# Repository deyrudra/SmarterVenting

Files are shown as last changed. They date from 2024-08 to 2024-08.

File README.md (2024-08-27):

# SmarterVenting
This is a Smarter Venting system that uses a hierarchy for prioritization of when to open vents, and at which degree.

*Note*: This is the main directory, which uses the esp8266 d1 mini microcontroller. The esp32 directory, using the LolinD32 (esp32) microcontroller.

Hierarchy:
1. Priority Rooms
   - Rooms above a garage.
   - Rooms with lack of insulation
   - Rooms with heating/cooling issues due to the size.
2. Secondary Rooms
   - Rooms that still need heating/cooling, but do not have any issues stated above.
3. Thermostat Location
  - Depending on the location, it could be an array of vents, or a singular vent.

Hierarchy concept:
- The general concept is as simple as reordering the rooms in which they get cool/hot air through.
- To prioritize the location of the thermostat last is to let the HVAC system run without stopping up until the Thermostat location reaches it's desired temperature.
  - This allows the other rooms to cooled/heated to it's desired temperature first.
 
Fallback:
- The temperature of the air coming from the vent; that is the limit to which you can cool/heat your room.

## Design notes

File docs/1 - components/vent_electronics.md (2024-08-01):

## Essential Parts (Mandatory)
- D1 Mini ESP8266
- MG90s Servo Motor

## Power Options (Mandatory, Choose One)
1. Plugged in USB-C or Micro-USB
    - Power Brick
    - USB-C or Micro-USB cable
2. Plugged in barrel connector w/ DC shield
    - D1 Mini DC Power Shield
    - Barrel Jack Power Cable
3. Battery Powered barrel connector w/ DC shield + AA batteries
    - D1 Mini DC Power Shield
    - Battery Holder to Barrel Jack 
    - AA Batteries (Prefereabbly Rechargeable)
4. Battery Powered USB-C or Micro-USB w/ PowerBank (my preffered option)
    - D1 Mini DC Power Shield
    - Powerbank (high capacity)

## My Personal List (This is just how I did it to make it dirt cheap)
- Some Items I bought, their quantity, and their price in CAD.
    - D1 mini v2
        - 1x 3.17
        - 3x 1.18
        - Total: 6.71
    - D1 mini v3
        - 4x 2.09
        - Total: 9.98
    - DHT11
        - 5x 0.89
        - Total: 4.45
    - US usb plug
        - 10x 1.24
        - Total: 12.40
    - Charging Cables USB C #1
        - 5x 1.00
        - 5x 1.00
        - Total: 10.00
    - Full Metal Servo 9g 5x
        - 5x 2.47
        - Total: 12.35
    - PowerBank 
        - 5x 7.99
        - Total: 45.15
    - PLA 1kg
        - Total: 15
- So for me the prices for the items are:
    - Single Vent Price:
        - 2.09
        - 2.47
        - 7.99
        - 0.25 x 15
        - Total: $16.30
    - Single Temperature Monitor Price:
        - 2.14
        - 4.45
        - 0.89
        - 1.00
        - 1.24
        - Total: $9.72
- For the powerbank, it's just a generic powerbank cover for a 2600mAh 18650 Rechargeable Battery.
    - The dimensions I found online are:
        - 96 x 24 x 23mm

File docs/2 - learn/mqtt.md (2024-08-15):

# MQTT
- MQTT stands for Message Queuing Telemetry Transport
- Messaging protocol used for communcation between IoT devices.
- Features of MQTT:
    - Publish/Subscribe Model:
        - Clients (our devices) *publish* messages to a model called a **broker**. This broker then redistributes these message to all subscribers of their respective topics.
    - Lightweight
    - Reliable
    - Scalability

- Publish/Subscribe (PUB/SUB) Model in Depth
    - Broker:
        - Receives all messages from publishers.
        - Filters the received messages based on topics.
        - Distributes the messages to appropriate subscribers
    - Topics:
        - A topic is just a string. It serves to route messages.
        - Topics resemble file paths: `home/kitchen/temperature`.
            - This means topics are hierarchial.
        - Publishers send messages to specific topics, subscribers express interest in one or more topics.
        
    - Publisher:
        - A device or application that sends messages to the broker under specific topics.
        - These publishers are only concerned about sending their data.
            - There is no concern about who the subscribers are, just need to send the data to the broker with the topic.
        - Ex. temperature sensor in smart home can publlish readings to the topic `home/kitchen/temperature`.
    - Subscriber:
        - A device or application that has interest in one or more topics.
        - Subscribers receive all messages published to their topic.
        - Ex. a smart thermostat might subscribe to `home/kitchen/temperature` to receive updates and adjust the temperature accordingly.
        - Under the hierarchy, if a subscriber chooses to, they can subscribe to multiple topics at once, without having to specifiy each one. They can just simply subscribe to `home/kitchen/#`. The `#` refers to all subtopics under the `home/kitchen` topic.

- QoS: QoS 1 ensures the message which has been published/subscribed to will establish connection atleast once. (ex. your device runs out of battery and you charge it back up, it will get the message after it's back alive).

- Retain: Allows published packets to keep it's value on the borker, such that the retained flags of the client act as a last save restoration, pulling info from the broker itself.
## Setting up an MQTT Broker on Home Assistant
- The guides I followed:
    - https://www.home-assistant.io/integrations/mqtt/#:~:text=press%20%E2%80%9CPUBLISH%E2%80%9D%20.-,Go%20to%20Settings%20%3E%20Devices%20%26%20services.,Select%20Publish.
    - https://github.com/home-assistant/addons/blob/master/mosquitto/DOCS.md
    - https://www.youtube.com/watch?v=WYyPMHqMV-w

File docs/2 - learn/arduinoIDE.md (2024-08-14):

- Instead of writing the script in a yaml configuartion on Home Assistant, I opted to type a script in Arduino. Then compile it into it's binary, and upload through OTA update on the hosted webserver.

- To start developing in the Arduino IDE for the ESP devices, we need to do the following:
    1. Install ESP8266 and ESP32 Add-on in Arduino IDE
        - Go to Preferences in the IDE, and put `https://dl.espressif.com/dl/package_esp32_index.json, http://arduino.esp8266.com/stable/package_esp8266com_index.json` for additional boards manager URLs.
    2. Open the Boards Manager, and install the ESP32 or ESP8266 boards manager.

- ESP8266WiFi Library: `https://arduino-esp8266.readthedocs.io/en/latest/esp8266wifi/readme.html`
- PubSubClient Library (MQTT): `https://www.arduino.cc/reference/en/libraries/pubsubclient/`

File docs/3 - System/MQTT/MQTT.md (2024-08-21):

# MQTT Topics and Payloads Documentation

## Overview
This document shares details on the project's MQTT topics, payloads, and their respective purposes used in the system. It also indicated when the topic should be QoS 0, QoS 1, and/or retain the published packets.
---

## 1. Topic Structure

### General Topic Format

### Topic Segments:
- **room**: The specific room (e.g., `room_1`, `room_2`).
- **component**: The device or sensor (e.g., `vent`, `dht_sensor`).
- **detail**: Depends on the device/sensor, documented below for the specific component.
- Ex. Full Topic: `room_1/vent/power_mode`
---

## 2. Topics
- Any "Get" topics are to be published by the components, and any "Set" topics are to be subscribed to by the components.

### 2.1 DHT Sensor Component

#### Get Current Temperature Celsius
- **Topic**: `room_x/dht_sensor/temperature/celsius`
- **Payload**: 
  - **Type**: null
  - **Description**: Request the current temperature in celcius from the sensor.
- QoS: 0

#### Get Current Temperature Ferenheit
- **Topic**: `room_x/dht_sensor/temperature/ferenheit`
- **Payload**: 
  - **Type**: null
  - **Description**: Request the current temperature in ferenheit from the sensor.
- QoS: 0

#### Get Current Humidity
- **Topic**: `room_x/dht_sensor/humidity`
- **Payload**: 
  - **Type**: null
  - **Description**: Request the current humidity percentage from the sensor.
- QoS: 0

#### Get Indicator Light Status
- **Topic**: `room_x/dht_sensor/light`
- **Payload**: 
  - **Type**: null
  - **Description**: Requests the current status of the light.
- QoS: 0
- Retain: True

#### Get Calibrate Offset
- **Topic**: `room_x/dht_sensor/calibrate`
- **Payload**: 
  - **Type**: null
  - **Description**: Requests the current temperature offset integer.
- Retain: True
 
#### Set Indicator Light Status
- **Topic**: `room_x/dht_sensor/light`
- **Payload**: 
  - **Type**: ON or OFF
  - **Description**: Sets the current status light to ON or OFF

#### Set Calibrate Offset
- **Topic**: `room_x/dht_sensor/calibrate`
- **Payload**: Any integer between -10 to 10
  - **Type**: int
  - **Description**: Offsets the temperature by an integer.

#### Last Will and Testament (LWT)
- **Topic**: `room_x/dht_sensor/status`
- **Payload**: "offline", "online"
- **QoS**: `1`
- **Retain**: `True`
- **Description**: Sent when the device goes offline unexpectedly.

### 2.2 Vent Component

#### Get Current Vent Angle
- **Topic**: `room_x/vent/angle`
- **Payload**: 
  - **Type**: null
  - **Description**: Request the current vent angle from the component.
- QoS: 1
- Retain: True
#### Get Current Vent Closure State
- **Topic**: `room_x/vent/closure_state`
- **Payload**: 
  - **Type**: null
  - **Description**: Request the current vent closure state from the component.
- QoS: 1
- Retain: True
#### Get Current Vent Power Mode
- **Topic**: `room_x/vent/power_mode`
- **Payload**: 
  - **Type**: null
  - **Description**: Request the current vent power mode from the component.
- QoS: 1
- Retain: True
#### Get Current Vent Climate Mode
- **Topic**: `room_x/vent/climate_mode`
- **Payload**: 
  - **Type**: null
  - **Description**: Request the current vent climate mode from the component.
- QoS: 1
- Retain: True
#### Get Current Vent Control Mode
- **Topic**: `room_x/vent/control_mode`
- **Payload**: 
  - **Type**: null
  - **Description**: Request the current control mode from the component.
- QoS: 1
- Retain: True
#### Get Current Vent Desired Temperature
- **Topic**: `room_x/vent/desired_temp`
- **Payload**: 
  - **Type**: null
  - **Description**: Request the desired temperature from the vent component.
- QoS: 1
- Retain: True

#### Get Desired Temperature Reached State
- **Topic**: `room_x/vent/desired_temp_state`
- **Payload**: 
  - **Type**: null
  - **Description**: Request to see if the desired temperature has been reached, or if it's still ongoing. YES for reached state, NO for not reached yet.
- QoS: 1
- Retain: True

#### Set Current Vent Angle
- **Topic**: `room_x/vent/angle`
- **Payload**: An integer between 0 and 90
  - **Type**: int
  - **Description**: Sets the current vent angle.
- QoS: 1

#### Set Current Vent Closure State
- **Topic**: `room_x/vent/closure_state`
- **Payload**: "Closed", "Semi-Closed", "Open", "Semi-Open"
  - **Type**: String
  - **Description**: Sets the current vent closure state.
- QoS: 1

#### Set Current Vent Power Mode
- **Topic**: `room_x/vent/power_mode`
- **Payload**: "Default", "Eco", "Max-Power"
  - **Type**: String
  - **Description**: Sets the current vent power mode.
- QoS: 1

#### Set Current Vent Climate Mode
- **Topic**: `room_x/vent/climate_mode`
- **Payload**: "Heating", "Cooling"
  - **Type**: String
  - **Description**: Sets the current vent climate mode.
- QoS: 1

#### Set Current Vent Control Mode
- **Topic**: `room_x/vent/control_mode`
- **Payload**: "Auto", "Manual"
  - **Type**: String
  - **Description**: Sets the current control mode.
- QoS: 1

#### Set Current Vent Desired Temperature
- **Topic**: `room_x/vent/desired_temp`
- **Payload**: Any integer between 17 to 26.
  - **Type**: int
  - **Description**: Sets the desired temperature.
- QoS: 1

#### Last Will and Testament (LWT)
- **Topic**: `room_x/vent/status`
- **Payload**: "offline", "online", "eco-online"
- **QoS**: `1`
- **Retain**: `True`
- **Description**: Sent when the device goes offline unexpectedly or due to eco mode.

---

## 3. QoS and Retain Flag

### Quality of Service (QoS)
- **QoS 0**: Best effort, no acknowledgment.
- **QoS 1**: Ensured delivery, message delivered at least once.
- **QoS 2**: Exactly once delivery, message is delivered only once.

### Retain Flag
- **True**: The last message sent on this topic is saved by the broker.
- **False**: The broker does not save the last message.

### Practical Reasons
- QoS: QoS 1 ensures the message which has been published/subscribed to will establish connection atleast once. (ex. your device runs out of battery and you charge it back up, it will get the message after it's back alive).
  - All vent control should be QoS 1 to increase user experience. 
- Retain: Allows published packets to keep it's value on the borker, such that the retained flags of the client act as a last save restoration, pulling info from the broker itself.

---

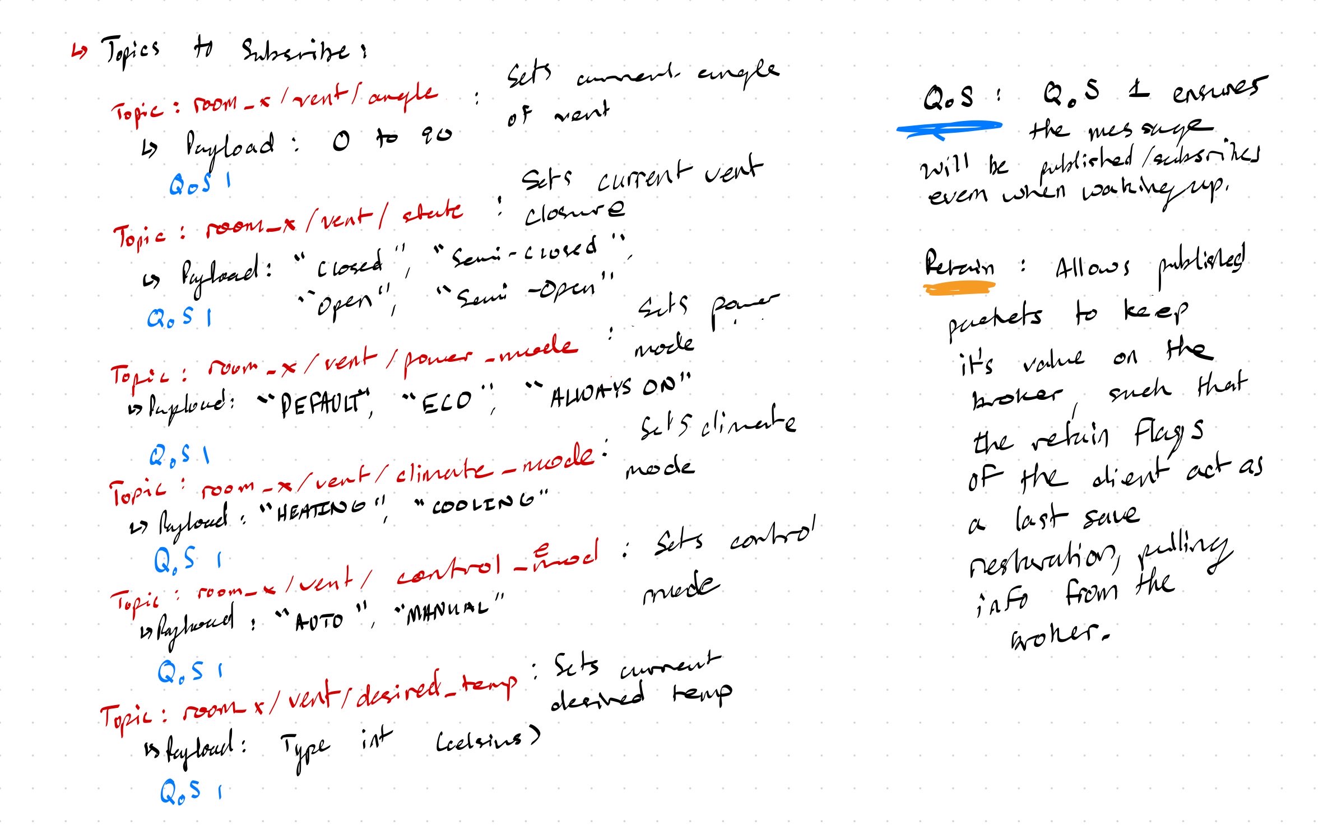
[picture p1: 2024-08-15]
docs/3 - System/MQTT/writtenbrainstorm/image.jpg

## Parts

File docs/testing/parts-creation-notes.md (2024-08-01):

Fins:
Clearance: 0.25cm
Border Margin Shrink: 0.1cm
Overlap: 0.4cm so 0.2 on each one. Also there is only 2 overlap areas.

Short Side
x: 2.87-0.1*2 = 4.3cm 
y: x/2 = 3/2 = 1.5cm

Cutouts must be at: 
Cut 1:
x: 1.6cm
y: 1.6cm
Cut 2:
x: 4.5cm
y: 1.6cm
Cut 3:
x: 7.4cm
y: 1.6cm

x = 1.6cm
y = 1.6cm

Long Side
23.7cm

- There will be 0.4 overlap in the two middle ones.

Joints
Circle: 

Male:

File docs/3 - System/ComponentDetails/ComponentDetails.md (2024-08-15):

# Component Details

## Overview
This document specifies the details of each component in the system. Under each component heading you will find the inner workings of the component and details of all it's processes and automations.

## 1. Vent

### Purpose (Primary Function)

### Processes (All Functions)

### Automations (Automatic executed functions)

## 2. Temperature Sensor

### Purpose (Primary Function)

### Processes (All Functions)

### Automations (Automatic executed functions)

## 3. Homeassistant + MQTT Broker Server

### Purpose (Primary Function)

### Processes (All Functions)

### Automations (Automatic executed functions)

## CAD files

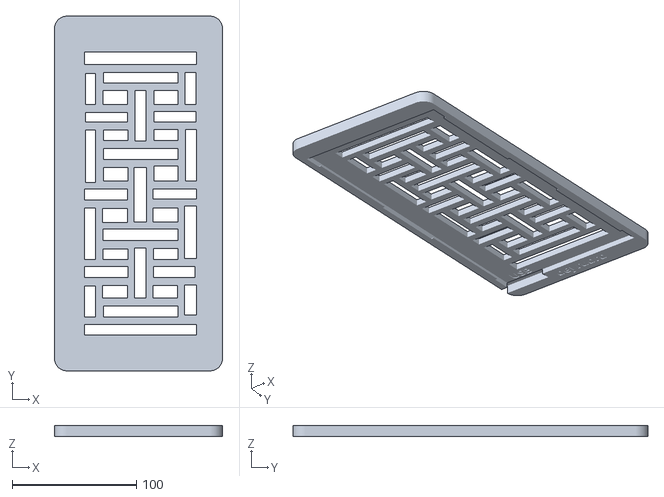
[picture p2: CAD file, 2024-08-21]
models/Register1 (4x10, 3.54x9.61)/Vent Cover/Vent Cover Full.stl
135.0 x 285.0 x 9.00

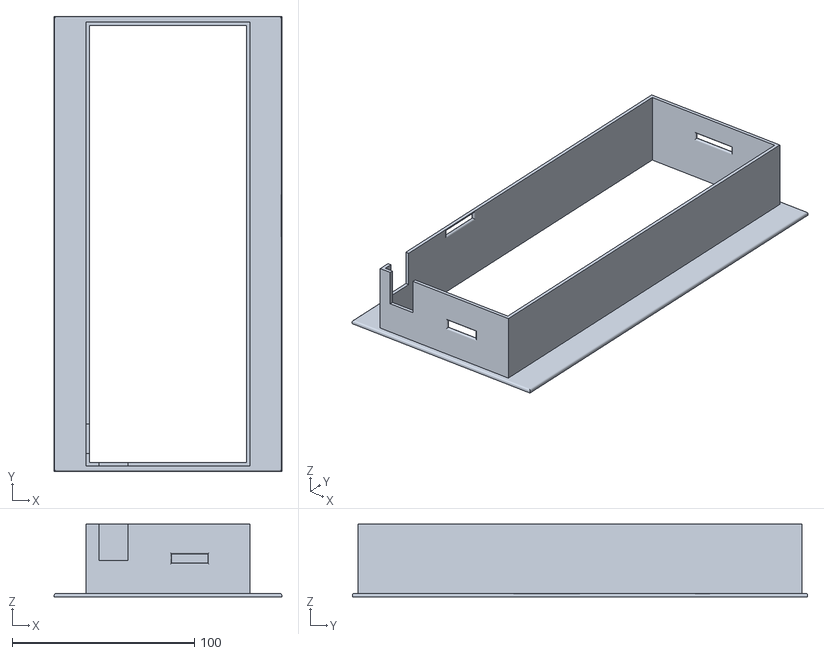
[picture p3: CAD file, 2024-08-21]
models/Register1 (4x10, 3.54x9.61)/Chasis/Chasis Full.stl
125.0 x 250.0 x 40.0

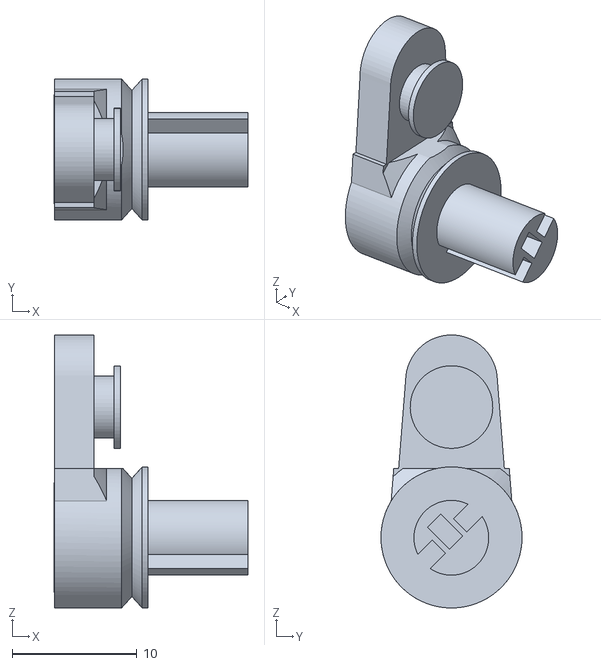
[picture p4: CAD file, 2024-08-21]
models/Register1 (4x10, 3.54x9.61)/Attachments/Lever (x4).stl
15.5 x 11.3 x 21.9

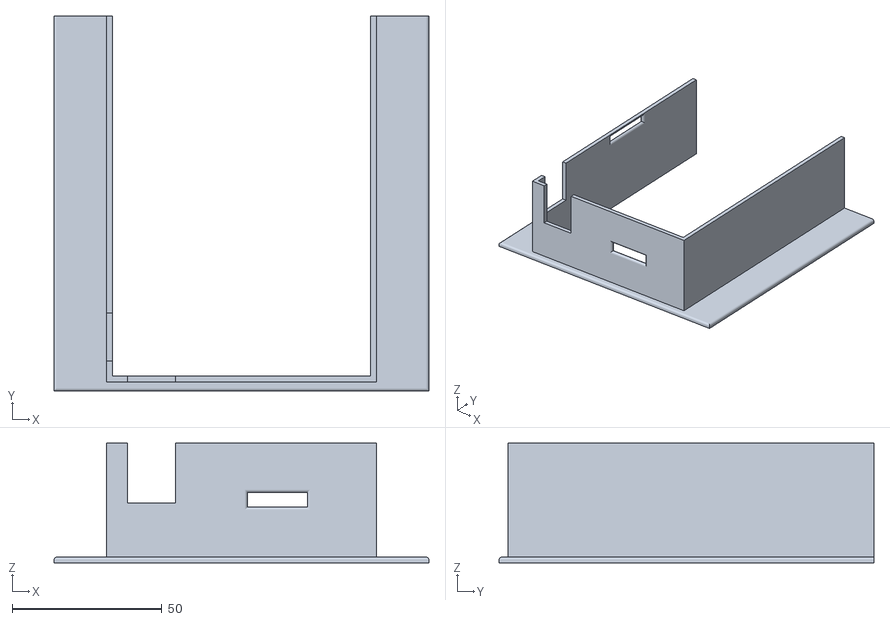
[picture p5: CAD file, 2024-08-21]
models/Register1 (4x10, 3.54x9.61)/Chasis/Chasis Part 1.stl
125.0 x 125.0 x 40.0

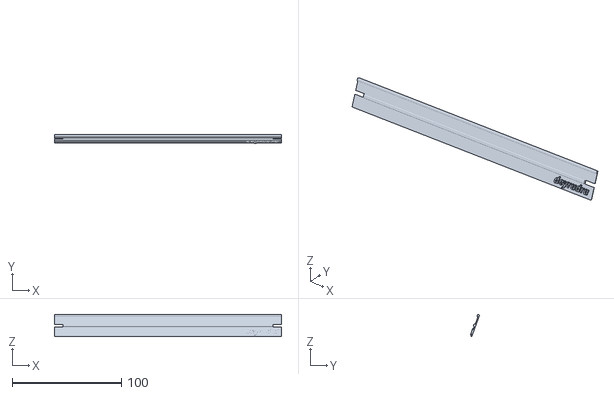
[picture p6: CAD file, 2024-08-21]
models/Register1 (4x10, 3.54x9.61)/Fins/Fin 4 (20.8 cm).stl
208.0 x 8.59 x 20.3

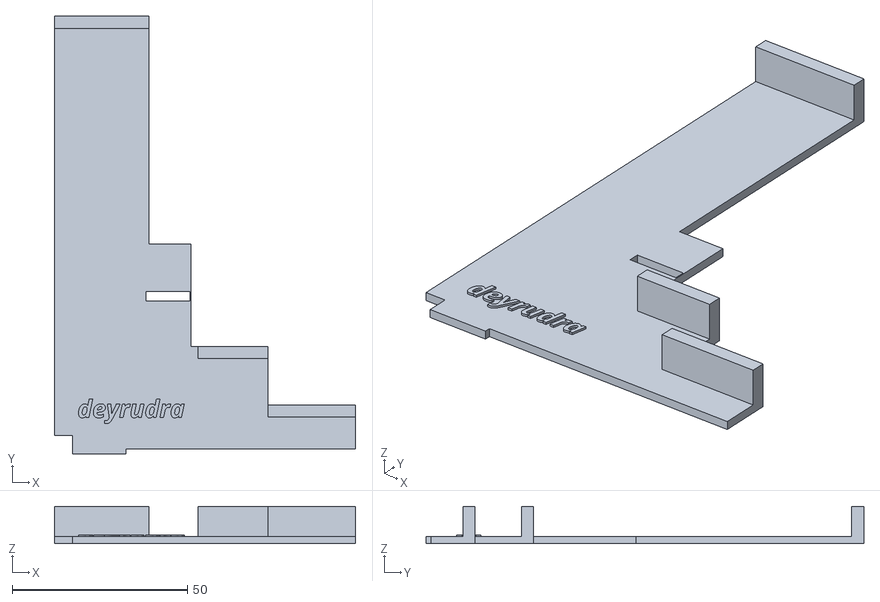
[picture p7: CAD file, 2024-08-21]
models/Register1 (4x10, 3.54x9.61)/Misc/Electronics Cover.stl
86.0 x 125.0 x 10.7

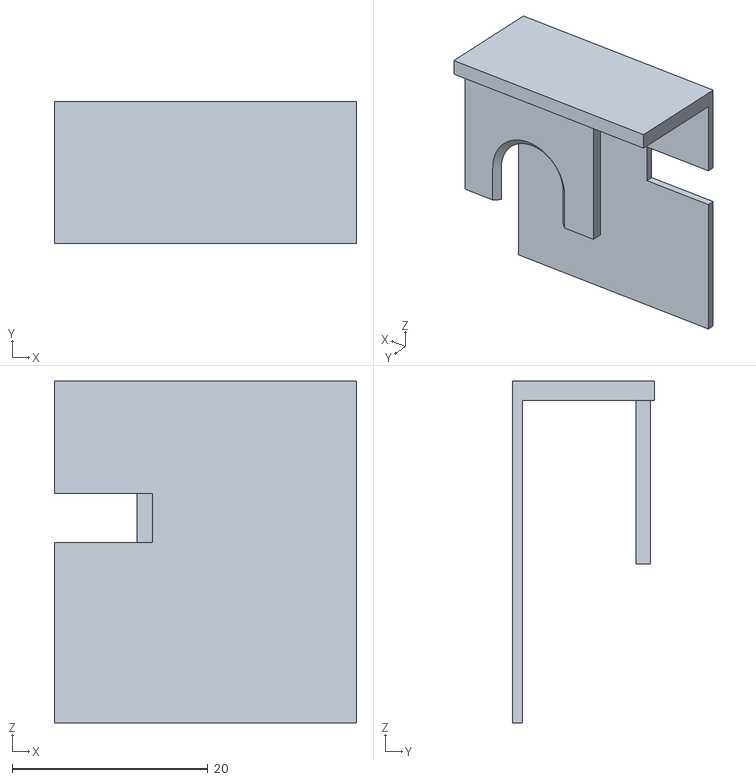
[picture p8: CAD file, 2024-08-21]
models/Register1 (4x10, 3.54x9.61)/Mount and Mount Headers/Right Mount.stl
30.9 x 14.5 x 34.9

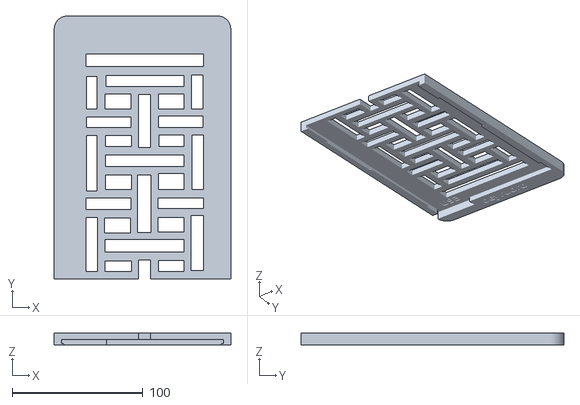
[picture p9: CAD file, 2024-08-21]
models/Register1 (4x10, 3.54x9.61)/Vent Cover/Vent Cover Part 2.stl
135.0 x 201.1 x 9.00

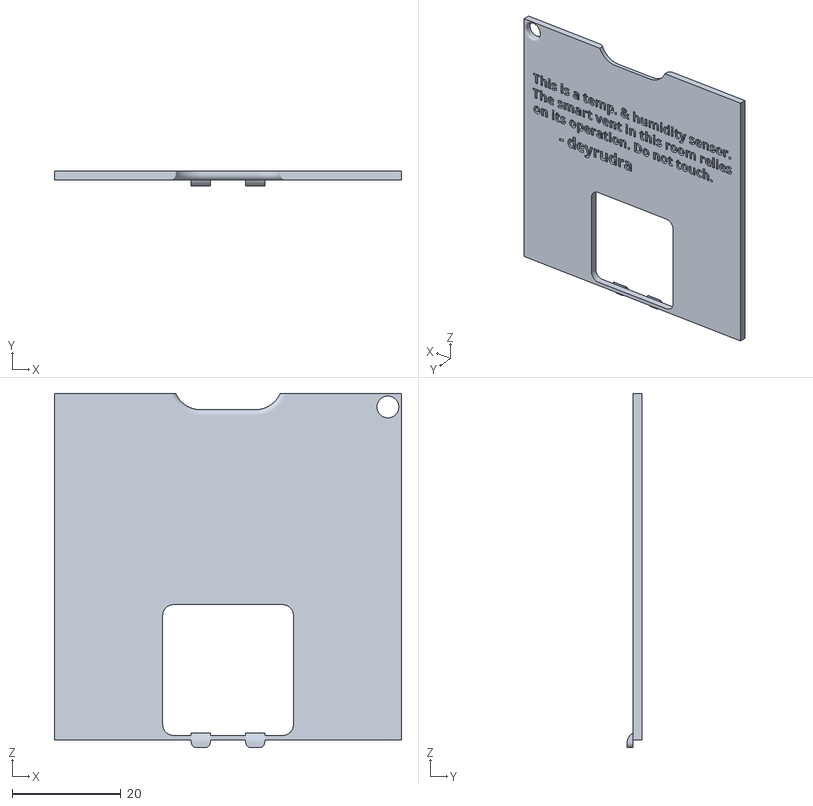
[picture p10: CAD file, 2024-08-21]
models/Sensor1 (US_plug, 2.75x2.75)/Sensor Module Cover.stl
63.7 x 2.71 x 65.0

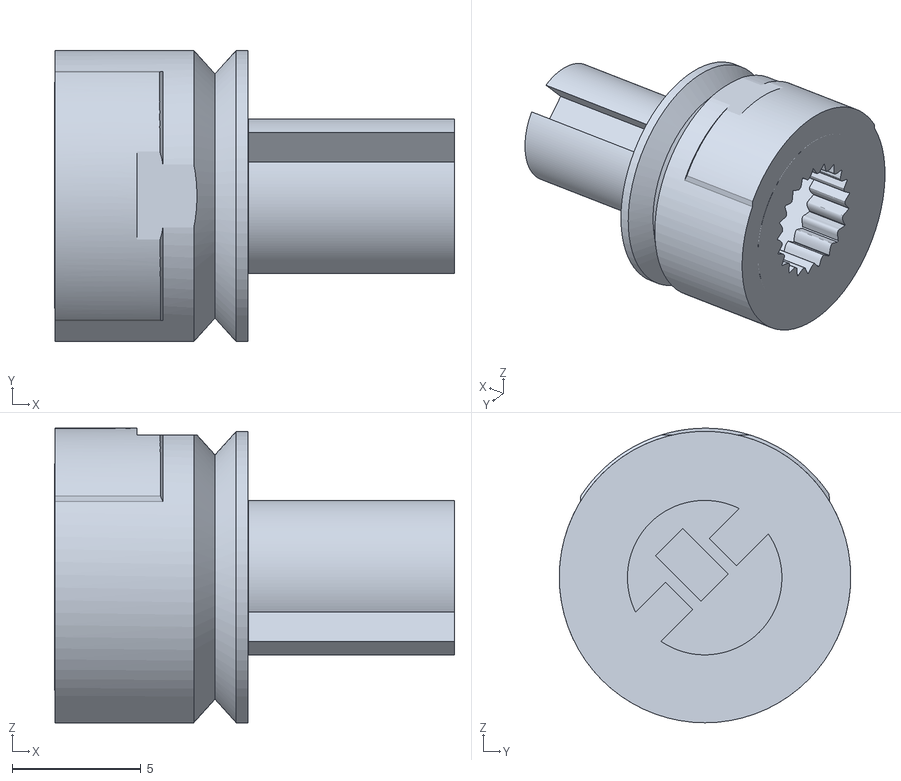
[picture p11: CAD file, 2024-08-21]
models/Register1 (4x10, 3.54x9.61)/Attachments/Circle (x4).stl
15.5 x 11.3 x 11.4

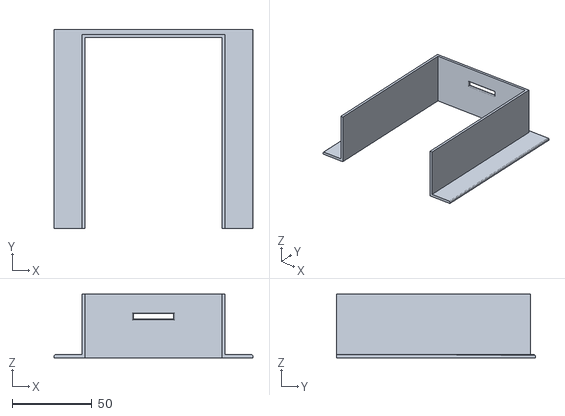
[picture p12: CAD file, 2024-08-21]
models/Register1 (4x10, 3.54x9.61)/Chasis/Chasis Part 2.stl
125.0 x 125.0 x 40.0

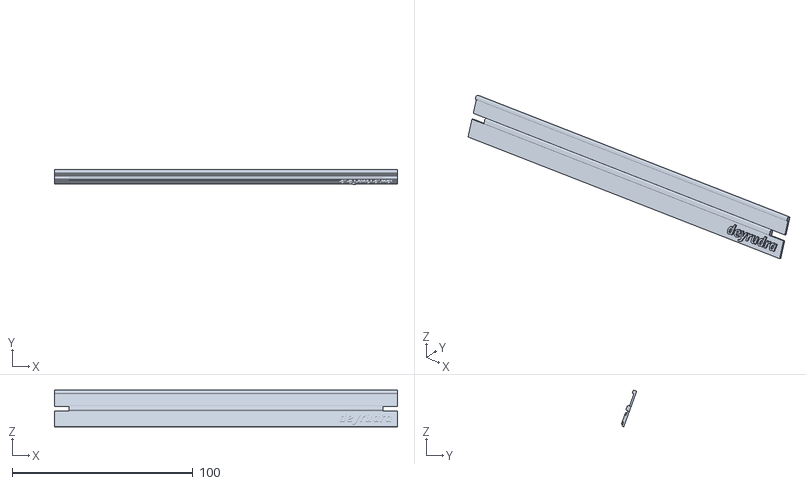
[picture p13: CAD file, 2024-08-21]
models/Register1 (4x10, 3.54x9.61)/Fins/Fin 3 (19 cm).stl
190.0 x 8.59 x 20.3

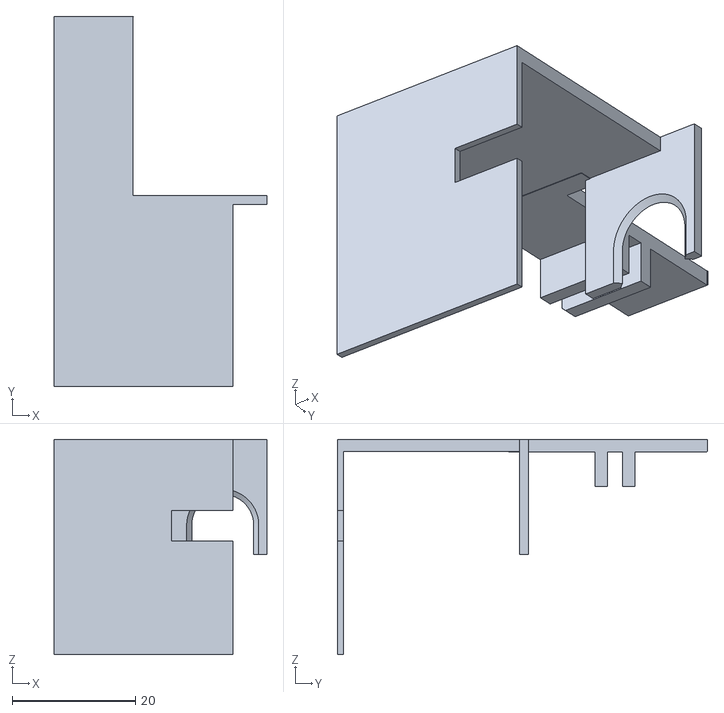
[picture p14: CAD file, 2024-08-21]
models/Register1 (4x10, 3.54x9.61)/Mount and Mount Headers/Middle Mount.stl
34.5 x 60.0 x 34.9

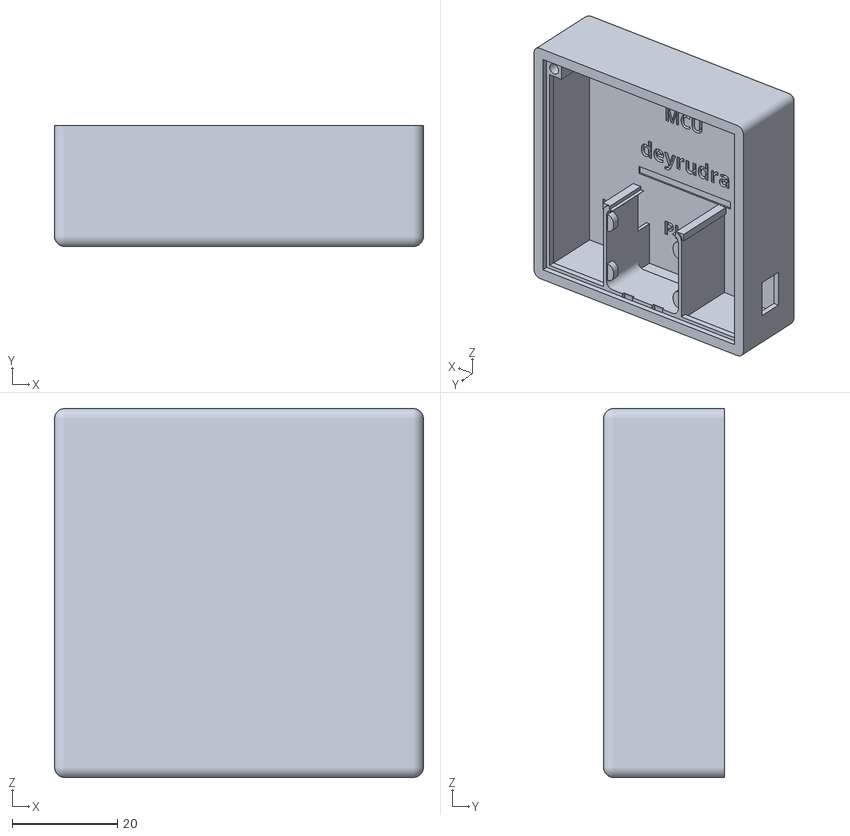
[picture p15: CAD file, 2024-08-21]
models/Sensor1 (US_plug, 2.75x2.75)/Sensor Module Body.stl
70.0 x 23.0 x 70.0

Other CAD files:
models/Register1 (4x10, 3.54x9.61)/Fins/Fin 2 (16 cm).stl
models/Register1 (4x10, 3.54x9.61)/Mount and Mount Headers/Left Mount.stl
models/Register1 (4x10, 3.54x9.61)/Fins/Fin 1 (9.4 cm).stl
models/Register1 (4x10, 3.54x9.61)/Mount and Mount Headers/Mount Header 1 (x3).stl
models/Register1 (4x10, 3.54x9.61)/Mount and Mount Headers/Mount Header 2.stl

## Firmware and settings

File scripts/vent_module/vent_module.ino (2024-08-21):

#include "secrets.h"

#include <ESP8266WiFi.h>
#include <ESP8266mDNS.h>
#include <WiFiUdp.h>
#include <ArduinoOTA.h>
#include <PubSubClient.h>
#include <Servo.h>

WiFiClient espClient;
PubSubClient client(espClient);
unsigned long lastMsg = 0;
#define MSG_BUFFER_SIZE	50
char msg[MSG_BUFFER_SIZE];
int value = 0;

int ledState;
int finAngle;
String closureState = "Open";
String powerState = "Max-Power";
String climateState = "Cooling";
String controlState = "Auto";
double desiredTemp = 22.0;
double currentTemp;
String desiredTempState;
Servo myServo;
const int SERVOPIN = 2;



void connect_wifi() { // Wifi Connection
  WiFi.mode(WIFI_STA);
  WiFi.begin(WIFI_SSID, WIFI_PASS);

  Serial.print("Connecting to the wifi...");
  while (WiFi.status() != WL_CONNECTED){
    delay(500);
    Serial.print(".");
  }
  Serial.println();

  Serial.print("Connected, IP Address: ");
  Serial.println(WiFi.localIP());

}

void connect_mqtt_broker() { // MQTT Connection
  client.setServer(MQTT_BROKER_IP, MQTT_BROKER_PORT);
  client.setCallback(callback);
}

void arduino_ota() {
  ArduinoOTA.setPassword((const char *)"123");
  ArduinoOTA.setPort(8266);
  ArduinoOTA.onStart([]() {
    Serial.println("Start");
  });
  ArduinoOTA.onEnd([]() {
    Serial.println("\nEnd");
  });
  ArduinoOTA.onProgress([](unsigned int progress, unsigned int total) {
    Serial.printf("Progress: %u%%\r", (progress / (total / 100)));
  });
  ArduinoOTA.onError([](ota_error_t error) {
    Serial.printf("Error[%u]: ", error);
    if (error == OTA_AUTH_ERROR) Serial.println("Auth Failed");
    else if (error == OTA_BEGIN_ERROR) Serial.println("Begin Failed");
    else if (error == OTA_CONNECT_ERROR) Serial.println("Connect Failed");
    else if (error == OTA_RECEIVE_ERROR) Serial.println("Receive Failed");
    else if (error == OTA_END_ERROR) Serial.println("End Failed");
  });
  ArduinoOTA.begin();
}

void moveVent(int angle) {
  moveServo(angle);

  if (angle == 0) {
    closureState = "Closed";
  }
  else if (0 < angle <= 22.5) {
    closureState = "Semi-Closed";
  }
  else if (22.5 < angle <= 67.5) {
    closureState = "Neutral";
  }
  else if (67.5 < angle <= 90) {
    closureState = "Semi-Open";
  }
  else if (angle == 90) {
    closureState = "Open";
  }
  else {
    closureState = "NULL";
  }
}


// Callback
void callback(char* topic, byte* payload, unsigned int length) { // Reading MQTT Messages
  char message[length];
  // Logging received topic and payload.
  Serial.println();
  Serial.print("Message arrived [");
  Serial.print(topic);
  Serial.print("] : ");
  memcpy(message, payload, length);
  message[length] = '\0';
  Serial.println(message);

  // Custom Commands (Set/Subscription)

  if (strcmp(topic, "room_1/vent/angle") == 0) {
    char* pEnd;
    double angle = strtod(message, &pEnd);
    if (0 <= angle <= 90){
      moveVent(angle);
    }
  }

  // if (strcmp(topic, "room_1/vent/closure_state") == 0) {
  //   if (strcmp(message, "Closed") == 0){
  //     moveVent(0);
  //   }
  //   if (strcmp(message, "Semi-Closed") == 0){
  //     moveVent(22.5);
  //   }
  //   if (strcmp(message, "Neutral") == 0){
  //     moveVent(45);
  //   }
  //   if (strcmp(message, "Semi-Open") == 0){
  //     moveVent(67.5);
  //   }
  //   if (strcmp(message, "Open") == 0){
  //     moveVent(90);
  //   }
  // } 

  if (strcmp(topic, "room_1/vent/power_mode") == 0) {
    // ("Default", "Eco", "Max-Power")
    if (strcmp(message, "Default") == 0) {
      powerState = "Default";
    }
    if (strcmp(message, "Eco") == 0) {
      powerState = "Eco";

    }
    if (strcmp(message, "Max-Power") == 0) {
      powerState = "Max-Power";

    }

  } 

  if (strcmp(topic, "room_1/vent/climate_mode") == 0) {
    // Current Vent Climate Mode ("Heating", "Cooling")
    if (strcmp(message, "Heating") == 0){
      climateState = "Heating";
    }
    if (strcmp(message, "Cooling") == 0){
      climateState = "Cooling";
    }
  } 

  if (strcmp(topic, "room_1/vent/control_mode") == 0) {
    // Current Vent Control Mode ("Auto", "Manual")
    if (strcmp(message, "Auto") == 0){
      controlState = "Auto";
    }
    if (strcmp(message, "Manual") == 0){
      controlState = "Manual";
    }
  } 

  if (strcmp(topic, "room_1/vent/desired_temp") == 0) {
    // 17 to 26 degrees
    char* pEnd;
    desiredTemp = strtod(message, &pEnd);
  } 

  if (strcmp(topic, "room_1/dht_sensor/temperature/celsius") == 0) {
    char *eptr;
    currentTemp = strtod(message, &eptr);
  }


  // if (strcmp(topic, "room_1/dht_sensor/light") == 0){
  //     if (strcmp(message,"OFF") == 0) {
  //       ledState = HIGH;// Turn the LED off
  //     } else if (strcmp(message,"ON") == 0) {
  //       ledState = LOW;// Turn the LED on
  //     }
  //     digitalWrite(BUILTIN_LED, ledState);  
  // }

  // if (strcmp(topic, "room_1/dht_sensor/calibrate") == 0){
  //   char *eptr;
  //   temp_offset_celsius = strtod(message, &eptr); // Need this for angle
  // }
}

void reconnect() {
  // Loop until we're reconnected
  while (!client.connected()) {
    Serial.print("Attempting MQTT connection...");
    // Create a random client ID
    String clientId = "temp_humidity_sensor_room_";
    clientId += String(random(0xffff), HEX);
    // Attempt to connect
    if (client.connect(clientId.c_str(), MQTT_USERNAME, MQTT_PASS, "room_1/vent/status", 1, true, "offline")) {
      // Connected succesfully.
      Serial.println("Succesfully connected to MQTT Broker!");

      // Sending a online status message.
      client.publish("room_1/vent/status", "online", true); 
      
      // Subscribing to topics
      client.subscribe("room_1/vent/#", 1);
      client.subscribe("room_1/dht_sensor/temperature/celsius", 1);
      client.subscribe("room_1/dht_sensor/humidity", 1);
      

    } else {
      // Trying to reconnect.
      Serial.print("Failed, rc=");
      Serial.print(client.state());
      Serial.println("Trying again in 10 seconds");
      // Waiting about 8 seconds before retrying
      for (int i = 0; i < 4; i++) {
        ledState = LOW;
        digitalWrite(BUILTIN_LED, ledState);
        delay(1000);
        ledState = HIGH;
        digitalWrite(BUILTIN_LED, ledState);
        delay(1000);
      }
    }
  }
}

void heatingCycle() {
  // Now based on the desired temperature, current temperature, and possibly outside temperature perform operations.
  if (currentTemp > (desiredTemp - 0.5)) {

    moveVent(0); // To NOT heat the current temp
    desiredTempState = "NO";
  }

  if ((desiredTemp - 0.5) <= currentTemp ) {
    if (currentTemp <= (desiredTemp + 0.5) ) {
      moveVent(45); // To maintain the current temperature
      desiredTempState = "YES";
    }
  }

  if (currentTemp < (desiredTemp + 0.5)) {
    moveVent(90); // To heat the current temp
    desiredTempState = "NO";
  }
}

void coolingCycle() {
  // Now based on the desired temperature, current temperature, and possibly outside temperature perform operations.
  if (currentTemp < (desiredTemp - 0.5)) {
    moveVent(0); // To NOT cool the current temp
    desiredTempState = "NO";
  }

  if ((desiredTemp - 0.5) <= currentTemp ) {
    if (currentTemp <= (desiredTemp + 0.5) ) {
      moveVent(45); // To maintain the current temperature
      desiredTempState = "YES";
    }
  }

  

  if (currentTemp > (desiredTemp + 0.5)) {
    moveVent(90); // To cool the current temp
    desiredTempState = "NO";
  }
  
}

void moveServo(int angle) {
  // Connect to Servo pin 2.
  angle = 90 - angle;
  angle = angle * 2;
  myServo.attach(SERVOPIN);
  myServo.write(angle);
  delay(3000);
  myServo.detach();
}

void setup() {
  // Serial Connection
  Serial.begin(115200);
  Serial.println();

  // Built in LED indicator
  pinMode(BUILTIN_LED, OUTPUT);

  // Connect ESP8266 to wifi
  connect_wifi();

  // Connect to MQTT broker
  connect_mqtt_broker();

  // Connect with Arduino OTA updates
  arduino_ota();  

}


void loop() {

  //PubSub Client
  if (!client.connected()) {
    reconnect();
  }
  client.loop();

  ArduinoOTA.handle(); // OTA Handler


  // Operations
  unsigned long now = millis();
  if (now - lastMsg > 5000) { // 5 second transfer
    lastMsg = now;

    //Test
    // 1s here

    // Current Vent Closure State ("Closed", "Semi-Closed", "Open", "Semi-Open")
    snprintf (msg, MSG_BUFFER_SIZE, "%s", closureState.c_str());
    Serial.print("Publish message: ");
    Serial.println(msg);
    client.publish("room_1/vent/closure_state", msg, true);
   
    // Current Vent Power Mode ("Default", "Eco", "Max-Power")
    snprintf (msg, MSG_BUFFER_SIZE, "%s", powerState.c_str());
    Serial.print("Publish message: ");
    Serial.println(msg);
    client.publish("room_1/vent/power_mode", msg, true);
   
    // Current Vent Climate Mode ("Heating", "Cooling")
    snprintf (msg, MSG_BUFFER_SIZE, "%s", climateState.c_str());
    Serial.print("Publish message: ");
    Serial.println(msg);
    client.publish("room_1/vent/climate_mode", msg, true);
   
    // Current Vent Control Mode ("Auto", "Manual")
    snprintf (msg, MSG_BUFFER_SIZE, "%s", controlState.c_str());
    Serial.print("Publish message: ");
    Serial.println(msg);
    client.publish("room_1/vent/control_mode", msg, true);
   
    // Current Vent Desired Temperature Reached State ("YES", "NO")
    snprintf (msg, MSG_BUFFER_SIZE, "%s", desiredTempState.c_str());
    Serial.print("Publish message: ");
    Serial.println(msg);
    client.publish("room_1/vent/desired_temp_reached", msg, true);

    // Offline Status ("offline", "online", "eco-online")
    snprintf (msg, MSG_BUFFER_SIZE, "online");
    Serial.print("Publish message: ");
    Serial.println(msg);
    client.publish("room_1/vent/status", msg, true);

    // Check powerState and loop depending on it's state.
    if (powerState.equals("Eco") || powerState.equals("Default")) { // Go into DeepSleep
      if (climateState.equals("Heating")){
        // Call heating cycle function
        heatingCycle();
      }
      if (climateState.equals("Cooling")){
        // Call cooling cycle function
        coolingCycle();
      }

      // Go to sleep code.


    }


    if (powerState.equals("Max-Power")) { // Operate Always
      if (climateState.equals("Heating")){
        // Call heating cycle function
        heatingCycle();
      }
      if (climateState.equals("Cooling")){
        // Call cooling cycle function
        coolingCycle();
      }

    }



  }
}

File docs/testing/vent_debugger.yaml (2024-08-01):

# This script allows you to go through from 0% to 100% of the servo range.
# Created by: deyrudra 2027-07-26

# Currently using a knockoff MG90 (metal gears). However for some reason after movement the motor
# seems to jitter in place. This doesn't happen in the Arduino IDE, only in ESPHome in HAOS.
# The fix I found was to put this after any Servo write operation:
  # - delay: 2s
  # - servo.detach:
  # id: my_servo
  # - output.turn_off: pwm_output


esphome:
  name: smartventrudra
  friendly_name: SmartVentRudra


esp8266:
  board: d1_mini


# Enable logging
logger:


# Enable Home Assistant API
api:
  encryption:
    key: "fzPuvc9uODtm0MpivgpgfTrQqtNR/uK4RER6ADW4JE0="


ota:
  - platform: esphome
    password: "b60757c696fc1334de0db2c6c406af73"


wifi:
  ssid: !secret wifi_ssid
  password: !secret wifi_password


  # Enable fallback hotspot (captive portal) in case wifi connection fails
  ap:
    ssid: "Smartventrudra Fallback Hotspot"
    password: "nmsitrvfmF86"


captive_portal:




# Servo setup


servo:
  - id: my_servo
    output: pwm_output
    transition_length: 0.6s


output:
  - platform: esp8266_pwm
    id: pwm_output
    pin: D3
    frequency: 50hz


button:
  - platform: template
    name: "test 1"
    on_press:
      then:
        - servo.write:
            id: my_servo
            level: 100%
        - delay: 2s
        - servo.detach:
            id: my_servo
        - output.turn_off: pwm_output
        
  - platform: template
    name: "test 2"
    on_press:
      then:
        - servo.write:
            id: my_servo
            level: 80%
        - delay: 2s
        - servo.detach:
            id: my_servo
        - output.turn_off: pwm_output

  - platform: template
    name: "test 3"
    on_press:
      then:
        - servo.write:
            id: my_servo
            level: 60%
        - delay: 2s
        - servo.detach:
            id: my_servo
        - output.turn_off: pwm_output

  - platform: template
    name: "test 4"
    on_press:
      then:
        - servo.write:
            id: my_servo
            level: 40%
        - delay: 2s
        - servo.detach:
            id: my_servo
        - output.turn_off: pwm_output

  - platform: template
    name: "test 5"
    on_press:
      then:
        - servo.write:
            id: my_servo
            level: 0%
        - delay: 2s
        - servo.detach:
            id: my_servo
        - output.turn_off: pwm_output

  - platform: template
    name: "test 6"
    on_press:
      then:
        - servo.write:
            id: my_servo
            level: -20%
        - delay: 2s
        - servo.detach:
            id: my_servo
        - output.turn_off: pwm_output

  - platform: template
    name: "test 7"
    on_press:
      then:
        - servo.write:
            id: my_servo
            level: -40%
        - delay: 2s
        - servo.detach:
            id: my_servo
        - output.turn_off: pwm_output

  - platform: template
    name: "test 8"
    on_press:
      then:
        - servo.write:
            id: my_servo
            level: -60%
        - delay: 2s
        - servo.detach:
            id: my_servo
        - output.turn_off: pwm_output

  - platform: template
    name: "test 9"
    on_press:
      then:
        - servo.write:
            id: my_servo
            level: -80%
        - delay: 2s
        - servo.detach:
            id: my_servo
        - output.turn_off: pwm_output

  - platform: template
    name: "test 10"
    on_press:
      then:
        - servo.write:
            id: my_servo
            level: -100%
        - delay: 2s
        - servo.detach:
            id: my_servo
        - output.turn_off: pwm_output


switch:
  - platform: template
    name: "Deep Sleep Control"
    id: deep_sleep_switch
    optimistic: true
    turn_on_action:
      - deep_sleep.prevent: deep_sleep_mode
    turn_off_action:
      - deep_sleep.enter: deep_sleep_mode

deep_sleep:
  id: deep_sleep_mode
  run_duration: 60s
  sleep_duration: 60s

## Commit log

2024-07-26 Update SmartVentDebugger.yaml
    Smart Vent Debugger is updated with a better and more effect jitter fix!
2024-08-21 vent_module.ino v1 done
    - User sets desired temperature, it automatically closes and opens to maintain this temperature.
    - Configured with ArduinoOTA, so wireless updates are possible through the Arduino IDE.
    - Does NOT support multiple vents / hierarchical system.
    [Sensor Module Body.stl, Sensor Module Cover.stl]
2024-08-21 Vent Model
    This is Version 1 of the 3D Printable MQTT Smart Vent.
    - Includes all parts to assemble the vent
    - This is a no screw design, instead it uses soldering iron to melt the joints of the print.
    Tools Required:
    - Soldering Iron (To solder the electronics, and melt some plastic)
    - 3d Printer
    Other Parts needed:
    - Servo
    - ESP32 or ESP8266 device. Currently I'm using an ESP8266, but DEEPSLEEP is not good. To make the device last a LOT longer, use a ESP32 microcontroller.
    - 18650 battery (I'm using a powerbank with a 18650 battery within, when I upgrade to ESP32 microcontroller I will ditch the powerbank because Deepsleep will pull too little current for the powerbank to actively push p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
    [Chasis Full.stl, Chasis Part 1.stl, Chasis Part 2.stl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]
2024-08-21 Sensor Module Updated
    - Update to version 1 of the Sensor Module.
    [Sensor Module Body.stl, Sensor Module Cover.stl]
